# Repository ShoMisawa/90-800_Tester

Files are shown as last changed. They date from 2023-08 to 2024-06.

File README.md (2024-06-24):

# 90-800 Tester Development (104252)
---
End of Project: September 2023 ; Continue to make improvement

Completed: Production team have requested to have confirmation button on the Top side.  This change has made on Rev A4.  Board not ordered yet.

Update: Op-Amp, TVS, Zener, Series Resistor, capacitor for the voltage measurement for 24VDC (Revision R5)
---
#### Instruction for T-867
1. Plug in 5V power supply to the left-hand side of the tester.
2.	Wait until display shows "Waiting for Power"
3.	Place device under test on top of the tester using two screws diagonally. Make sure that the rocker switch of the device under test is in OFF position.
4.	Make connections from the tester to the device under test (Input of the transformer, output of the transformer, Fire Loop, Voltage Output 1, and Voltage Output 2 Connection)
5.	Lastly, insert the main AC plug into the device.
6.	Turn on the AC main switch.
7.	Switch ON the rocker switch. This will initiate the testing process.
8.	The tester display will show the Voltage Output measurements. Adjust the output voltage via potentiometer to 24VDC (23 - 25VDC). Push the confirm button located on the right bottom side of the tester.
9.	The tester will go through Fire Loop functionality test next and upon completion, the tester will display the result.
10.	If the display shows "Test Good", turn off the AC power switch and remove the AC power connection from the device under test.
11.	Remove other wire connections and remove the device under test.

Note:
- If the output voltage potentiometer is not within the range, the tester may not be able to detec the power presense and sit in the "Waiting for Power" state.  Adjust the voltage to acceptable level using potentiometer with rocker switch on until voltage measurement shows on the display.
- This has changed to 10V for detection.
---
#### Altium Project File
 - [Project File](https://detex-corporation.365.altium.com/designs/327D70DE-DD06-426B-8618-25C8A5CFA4D7#design)
 - Based on Seeed Studio XIAO SAMD21 Board [Link](https://www.seeedstudio.com/Seeeduino-XIAO-Arduino-Microcontroller-SAMD21-Cortex-M0+-p-4426.html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)
 - [Datasheet](https://files.seeedstudio.com/wiki/Seeeduino-XIAO/res/ATSAMD21G18A-MU-Datasheet.pdf)
 - To program this micro, short the pads twice to put the device into programming mode

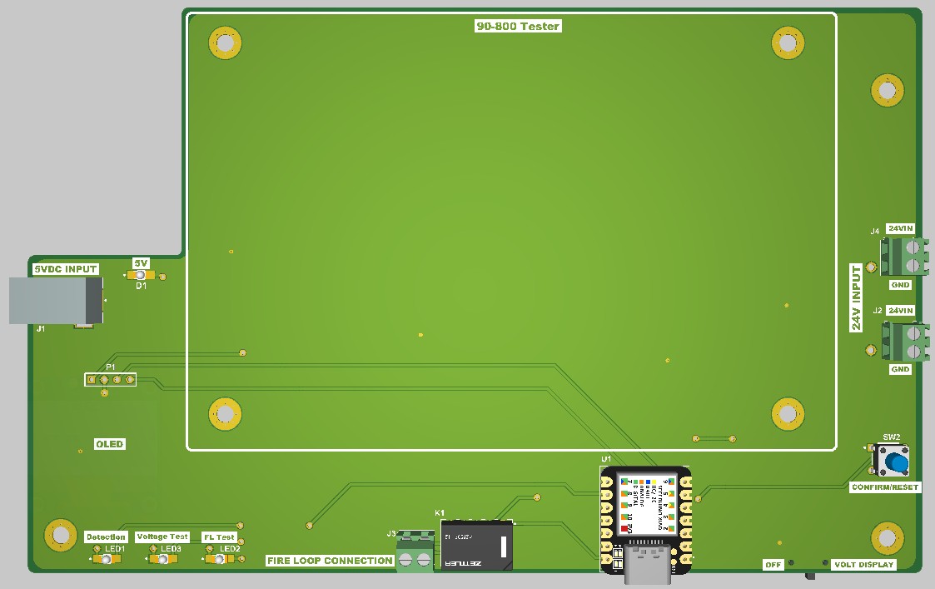
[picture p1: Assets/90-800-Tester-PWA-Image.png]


---
#### Tester Development Note
- Tester is utilizing the 11-800 Logic Controller Enclosure and trandformer.
- [Custom made PCB mount](3D Model/tester_with_cutout.3mf) that fits inside this enclosure 
- Using 3M screws as default
- 90 Degree 5V 5.5mm X 2.5mm US Plug
- 5V 1A power Adapter(typically used for LED strip etc)
  - [Used on this project](https://www.amazon.com/dp/B0C1NNZH87?psc=1&ref=ppx_yo2ov_dt_b_product_details)
    
---

### Bootloader for XIAO

- [Bootloader](https://github.com/Seeed-Studio/ArduinoCore-samd/blob/master/bootloaders/XIAOM0/bootloader-XIAO_m0-v3.7.0-33-g90ff611-dirty.bin)
- [Wiki](https://wiki.seeedstudio.com/Software-SWD/)
- [Tutoriak](https://embeddedcomputing.weebly.com/seeeduino-xiao-m0.html)
- [Xiao Expansion Board](https://embeddedcomputing.weebly.com/the-5-programmer-debugger.html)
- SWDIO and SWCLK are located on the bottom side of the board

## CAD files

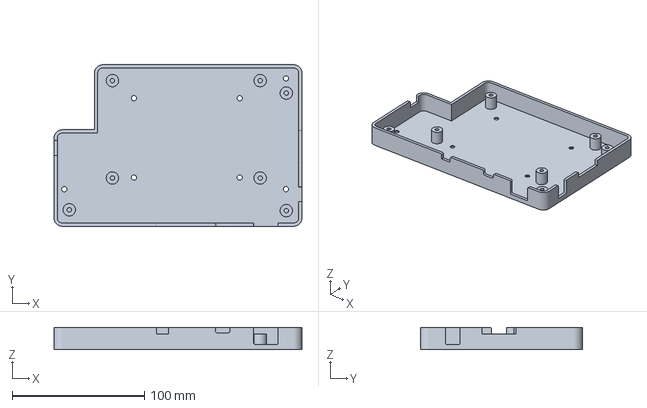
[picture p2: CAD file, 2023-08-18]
3D Model/tester_with_cutout.3mf
187.6 x 122.2 x 17.0 mm

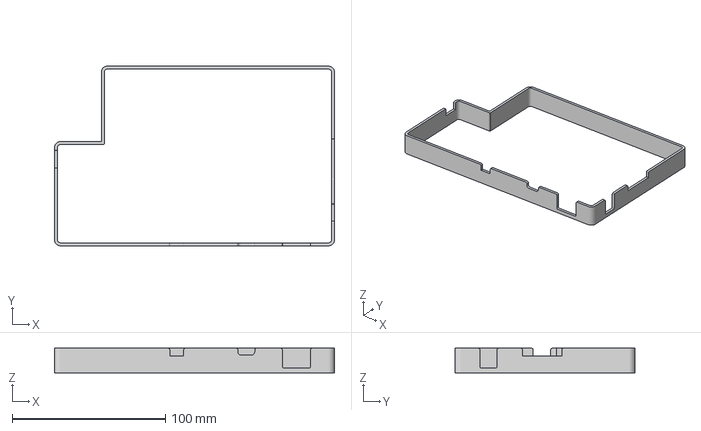
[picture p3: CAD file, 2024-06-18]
3D Model/90800_Filler.3mf
182.6 x 117.2 x 16.0 mm

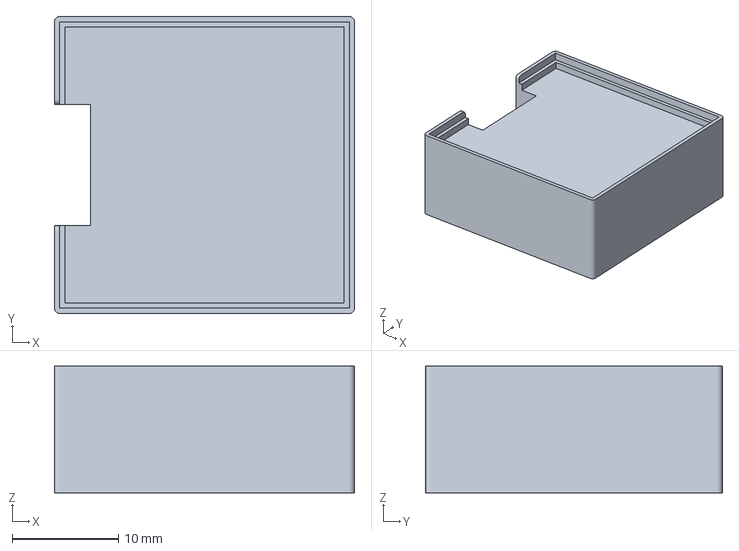
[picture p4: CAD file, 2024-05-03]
3D Model/90800_OLED_STAND.3mf
28.2 x 27.9 x 11.9 mm

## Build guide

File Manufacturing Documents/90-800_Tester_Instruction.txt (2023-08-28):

Instruction for T-XXX
1.  Plug in 5V power supply to the left hand side of the tester
2.  Wait until display shows "Waiting for Power"
3.  Place device under test on top of the tester using two screws diagnolly.  Make sure that the rocker switch of the device under test is in OFF position.
4.  Make connections from the tester to the device under test (Input of the transformer, output of the transformer, Fire Loop, Voltage Output 1, and Voltage Output 2 Connection)
5.  Lastly, insert main AC plug into the device
6.  Turn on the AC main switch
7.  Switch ON the rocker switch.  This will initiate the testing process.
8.  The tester display will show the Voltage Output measurements.  Adjust the output voltage via potentiometer to 24VDC (23 - 25VDC).  Push confirm button located on the right bottom side of the tester.
9.  Tester will go through Fire Loop functionality test next and upon completion, the tester will display the result.
10. If display shows "Test Good", turn off the AC power switch and remove the AC power connection on device under test.
11. Remove other wire connections and remove the device under test
12.

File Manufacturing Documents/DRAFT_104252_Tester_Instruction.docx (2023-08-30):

Reviewed By | Date | Compiled By | Date
| | SM | 8-25-2023

1.0 EQUIPMENT NEEDED

QTY ITEM

1 T-867 Tester
1 104252 Power Supply PWA
1 5V Plug-in Power Supply

1 AC Power Switch

2.0 SETUP

2.1. Plug in 5V wall power supply to the wall and wait until the display shows “Waiting for

Power”

2.2 Place 104252 PWA on top of the tester using two screws diagonally. Make sure that the rocker

ON/OFF switch is in OFF position.

2.3 Make connections from the tester to the device under test (Input of the transformer, output of

the transformer, Fire Loop, Voltage Output 1, and Voltage Output 2 Connection).

2.4 Lastly, insert the main AC plug into the device.

3.0 PROCEDURE

3.1 Turn ON the AC power switch.

3.2 Turn ON the rocker switch that is attached to 104352. LED1 on PWA should light up

GREEN.

3.3 The tester display will show the Voltage Output measurements. Adjust the output voltage via

potentiometer, V_Out Adjust, to 24VDC. Push the confirm button located on the right bottom

side on the tester.

3.4 Upon confirmation, the tester will automatically go through the Fire Loop functionality test.

3.5 If the display shows “Test Good,” turn off the AC power switch and remove the AC power

connection from the result.

3.6 Remove other wire connections and remove the device under test.

3.7 Test Complete.

Detex Manufacturing Test Procedure Pg1 Test Number Rev Date Description T-867 8-25-23 104252 Power Supply Board Test

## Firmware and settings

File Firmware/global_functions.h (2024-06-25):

#ifndef GLOBAL_FUNCTIONS_H
#define GLOBAL_FUNCTIONS_H

#include <Adafruit_SleepyDog.h>
#include <Arduino.h>
#include <U8g2lib.h>
#include <Wire.h>
#include <SPI.h>
#include "graphics.h"
//#include "global_variables.h"

/* Function Declarations */
void resetParameters();                                         // Function to reset used parameters for each cycle
void updateDisplay();                                           // Update the display to show the voltage measurements on OLED screen
void GPIO_setup();                                              // GPIO Initialization
void OLED_init();                                               // OLED Initialization
void WATCHDOG_init();                                           // Watchdog Initialization
void OLED_FL_OK_Screen();                                       // OLED FL Screen Update
void OLED_Relay_Animation();                                    // OLED Relay Screen Update
void OLED_waiting_for_power();                                  // OLED Waiting for Power Screen Update
float voltMeasure(int channel);                                 // Measuring/Reading the channel
void checkVoltage();                                            // Checking the voltage using voltMeasure function
void displayVoltageReading(float voltage, float voltage_2);     // OLED display the voltage when the toggle switch is ON
void reset_voltage_validation();                                // Resetting the voltage validation flag for FL test

void LED_TEST_ALLON();                                          // Turn on all the test result LEDs to make sure that soldered correctly.

/*------------------------------------------------------------------------------------------------------------------------*/
/*U8G2 Initialization*/
U8G2_SSD1306_128X64_NONAME_F_HW_I2C u8g2(U8G2_R0, /* reset=*/U8X8_PIN_NONE);  // initialization for the used OLED display
/*------------------------------------------------------------------------------------------------------------------------*/

void reset_voltage_validation(){
  voltageValidation_1 = 0;
  voltageValidation_2 = 0;
}

void checkVoltage() {
  /* Measuring the voltage */
  in_voltage = voltMeasure(0);
  in_voltage_2 = voltMeasure(1);
}

void OLED_FL_OK_Screen() {
  u8g2.setBitmapMode(1);
  u8g2.clearBuffer();
  u8g2.drawFrame(2, 3, 125, 61);
  u8g2.setFont(u8g2_font_haxrcorp4089_tr);
  u8g2.drawStr(33, 12, "Fire Loop Test");
  u8g2.drawLine(2, 14, 126, 14);
  u8g2.drawXBMP(51, 26, 24, 24, image_icons8_outline_effect_tickmark_under_a_square_box_24_bits);
  u8g2.sendBuffer();
}

void OLED_Relay_Animation() {
  u8g2.setBitmapMode(1);
  u8g2.clearBuffer();
  u8g2.drawFrame(2, 2, 125, 61);
  u8g2.drawLine(2, 14, 126, 14);
  u8g2.setFont(u8g2_font_haxrcorp4089_tr);
  u8g2.drawStr(51, 30, "Relay");
  u8g2.setFont(u8g2_font_haxrcorp4089_tr);
  u8g2.drawStr(33, 12, "Fire Loop Test");
  u8g2.drawXBMP(50, 34, 30, 30, aepd_bitmap_allArray[counterGraphics]);
  u8g2.sendBuffer();
  counterGraphics = (counterGraphics + 1) % 11;
}

void OLED_waiting_for_power() {
  u8g2.clearBuffer();
  u8g2.setBitmapMode(1);
  u8g2.drawFrame(2, 2, 123, 61);
  u8g2.setFont(u8g2_font_helvB08_tr);
  u8g2.drawStr(17, 29, "Waiting for Power");
  u8g2.drawXBMP(45, 35, 30, 30, epd_bitmap_allArray[counterGraphics]);
  u8g2.sendBuffer();  // transfer internal memory to the display
  counterGraphics = (counterGraphics + 1) % 29;
}

void WATCHDOG_init() {
  int wdtTimeout = Watchdog.enable(8000);  // Enable WDT with 8 seconds timeout
  Serial.print("WDT set to ");
  Serial.print(wdtTimeout, DEC);
  Serial.println(" milliseconds");
}

void OLED_init() {
  u8g2.begin();  // start the u8g2 library...
  u8g2.clearBuffer();
  u8g2.setBitmapMode(1);
  u8g2.drawXBMP(15, -1, 100, 70, image_detex_bits);
  u8g2.sendBuffer();
}

void GPIO_setup() {
  pinMode(BUTTON_PIN, INPUT_PULLUP);                  // this line also has external pullup resistor
  pinMode(VOLTAGE_DISPLAY_TOGGLE_PIN, INPUT_PULLUP);  // this line also has external pullup resistor

  pinMode(LED_8_PIN, OUTPUT);
  pinMode(LED_9_PIN, OUTPUT);
  pinMode(LED_10_PIN, OUTPUT);
  pinMode(RELAY_PIN, OUTPUT);

  digitalWrite(LED_8_PIN, LOW);
  digitalWrite(LED_9_PIN, LOW);
  digitalWrite(LED_10_PIN, LOW);
  digitalWrite(RELAY_PIN, HIGH);

  analogReadResolution(12);
}

void resetParameters() {
  voltageValidation_1 = 0;
  voltageValidation_2 = 0;

  voltageDetected = 0;  // upon power connection to 24V, this flag is set to 0 when it is less than 15V.  Set to 1 when it is greater than 15V.  15V is random value.

  state = 0;

  //previousMillis;
  count = 1;  // for development purpose, it is set to the state

  relayActiveFlag = 0;
  powerDetectionOK = 0;
  VoltageTestOK = 0;
  FLTestOK = 0;

  digitalWrite(LED_8_PIN, LOW);
  digitalWrite(LED_9_PIN, LOW);
  digitalWrite(LED_10_PIN, LOW);
  digitalWrite(RELAY_PIN, HIGH);
}

float voltMeasure(int channel) {
  analogReadResolution(12);

  if (channel == 0) {

    adc_value = analogRead(channel);
    adc_voltage = (adc_value * ref_voltage) / 4095.0;
    in_voltage = adc_voltage / resRatio;
    return in_voltage;
  }

  if (channel == 1) {

    adc_value_2 = analogRead(channel);
    adc_voltage_2 = (adc_value_2 * ref_voltage) / 4095.0;
    in_voltage_2 = adc_voltage_2 / resRatio;
    return in_voltage_2;
  }

}  // end of voltMeter function

/* Function to update display */
void updateDisplay() {
  u8g2.setBitmapMode(1);
  u8g2.clearBuffer();
  u8g2.drawFrame(2, 2, 124, 62);
  u8g2.drawLine(3, 15, 125, 15);

  u8g2.setFont(u8g2_font_9x15B_mr);
  //u8g2.drawStr(27, 30, "J6:");

  u8g2.setFont(u8g2_font_9x15B_mr);
  sprintf(voltagebuffer, "J6: %.2f", in_voltage);

  u8g2.drawStr(10, 30, voltagebuffer);
  u8g2.setFont(u8g2_font_9x15B_mr);
  u8g2.drawStr(83, 30, "V");
  u8g2.setFont(u8g2_font_haxrcorp4089_tr);
  u8g2.drawStr(30, 13, "Voltage Reading");
  u8g2.setFont(u8g2_font_9x15B_mr);
  //u8g2.drawStr(27, 45, "J7:");
  u8g2.setFont(u8g2_font_9x15B_mr);
  sprintf(voltagebuffer, "J7: %.2f", in_voltage_2);
  u8g2.drawStr(10, 45, voltagebuffer);
  u8g2.setFont(u8g2_font_9x15B_mr);
  u8g2.drawStr(83, 45, "V");
  u8g2.sendBuffer();
}
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

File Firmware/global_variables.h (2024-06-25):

#ifndef _GLOBAL_VARIABLES_H
#define _GLOBAL_VARIABLE_H

/*------------------------------------------------------------------------------------------------------------------------*/
/* Definitions*/
// OLED Screen Pixel Size
#define SCREEN_WIDTH                128           // OLED display width, in pixels
#define SCREEN_HEIGHT               64            // OLED display height, in pixels

// Voltage Upper and Lower Limit
#define upperLimit                  24*(1+0.1)    // 10% upper limit
#define lowerLimit                  24*(1-0.1)    // 10% lower limit

// Acceptable Power detection
#define powerLevel                  15

/*Pin Definitions*/
#define LED_8_PIN                   8             // Pin 8 (Port A): LED for Power Ditection
#define LED_9_PIN                   9             // Pin 9 (Port A): LED for Voltage Level
#define LED_10_PIN                  10            // Pin 10 (Port A): LED for Fire Loop test
#define RELAY_PIN                   7             // Pin 7 (Port A): Relay Control
#define BUTTON_PIN                  2             // Pin 2 (Port A): Button Read
#define VOLTAGE_DISPLAY_TOGGLE_PIN  3             // Pin 3 (Port A): Option to view the voltage level at the end of the test

// Debug Mode
#define LED_TEST_MODE                0             // This mode can be used to check the LED brightness for LED8, 9, and 10
/*------------------------------------------------------------------------------------------------------------------------*/

const float SCHOTTKY_VOLTAGE_DROP = 0.3;

/*------------------------------------------------------------------------------------------------------------------------*/
float R1 = 100000;                          // 100K Ohm
float R2 = 10000;                           // 10K Ohm
float resRatio = R2 / (R1 + R2);            // Calculating the ratio

/*Voltage Reading Parameters*/
float ref_voltage = 3.3;                    // Reference voltage of 3V3

// Bot J6
float adc_voltage = 0.0;                    // ADC reading for J6
float in_voltage = 0.0;                     // Converted voltage level
int adc_value = 0;                          // Converted value

// Top J9
float adc_voltage_2 = 0.0;                  // ADC reading for J9
float in_voltage_2 = 0.0;                   // Converted Voltage Level
int adc_value_2 = 0;                        // Converted Value

/*Test Confirmation Flags*/
int voltageValidation_1 = 0;                // Flag if J9 reads proper voltage level
int voltageValidation_2 = 0;                // Flag if J6 reads proper voltage level
int voltageDetected = 0;                    // upon power connection to 24V, this flag is set to 0 when it is less than 15V.  Set to 1 when it is greater than 15V.  15V is random value.

// Toggle Display
volatile bool showVoltage = false;

// State Switch Parameter
int state = 0;

//unsigned long previousMillis;
int count = 1;                              // for development purpose, it is set to the state

int relayActiveFlag = 0;
int powerDetectionOK = 0;
int VoltageTestOK = 0;
int FLTestOK = 0;

// Buffer for conversion to string
char buffer[32];

// Visibility Flags for Graphics
bool iconVisible = true; // default should be true
bool voltageCheckVisible = false; // default should be false
bool relaySwitchVisible = true; // default should be true

// Flashing graphics parameters
const long interval = 1000; // Flash interval for the icon in millisecond
unsigned long previousMillis = 0;
unsigned long currentMillis = 0;
char voltagebuffer[32]; // helper buffer to construct a string to be displayed

int counterGraphics = 0;
char graphicsBuffer[32];
int counterGraphics2 = 0;
/*------------------------------------------------------------------------------------------------------------------------*/


#endif

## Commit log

2023-08-26 Added simple python script to check the voltage divider
2023-08-28 Organized
    Organized
    [tester_with_cutout.3mf]
2023-08-28 Adding toggle and lower the detection voltage from 15 to 10
2023-08-28 Update 90800-Tester.ino
    Adding voltage read at the end of the test for further adjustment. And code cleanup.
2023-08-29 Update 90800-Tester.ino
    Fixed the issue with not separately reading two output voltage.
    [90800-Tester.ino]
2023-08-31 Update README.md
    Update note added for R4 with confirmation button on the top
2023-11-16 Switched to U8G2 Library for the OLED
2023-11-20 Adjusted the voltage reading display
    Voltage reading is more readable and also got rid of the "check" mark when voltage is within the range
